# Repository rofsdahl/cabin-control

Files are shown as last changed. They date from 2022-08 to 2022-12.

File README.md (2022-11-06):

# Introduction
Temperature control system for use in a remote location (e.g. a mountain cabin).

The system consists of an ESP32 microcontroller from Espressif and one or more Dallas/Maxim DS18B20 digital temperature sensors. The desired temperature is achieved by continuously switching on/off one or more electrical heaters using Nexa power plugs (over RF 433 MHz). The ESP32 device periodically connects to the Internet over WiFi, logging the current temperature into a Google spreadsheet. The spreadsheet is also used for setting the desired temperature, which will be transferred to the device during the next synchronization.

The ESP32 code is written in Arduino-style C/C++. Integration with Google spreadsheet is done using Google Apps Script (javascript).

## User interface

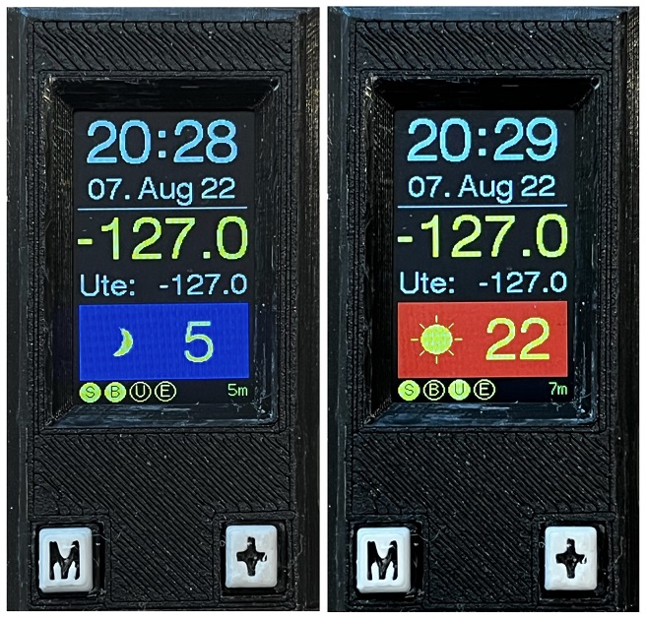
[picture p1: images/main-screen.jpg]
Main screen


The top section displays current date and time. This is updated using NTP, and will be automatically adjusted for DST (daylight saving time). The main temperature is displayed in yellow. Below, the display will cycle through any additional temperature sensors.

The currently set temperature is displayed, and the current temperature mode is indicated:
* :blue_square: :crescent_moon:: frost protection
* :red_square: :sunny:: comfort mode

The bottom line displays the current status of configured power plugs:
* ○: off
* ●: on

The current device activity is displayed at bottom right:
* **Nexa:** Device is transmitting control signals to power plugs (every 5 minutes)
* **WiFi:** Device is connecting to WiFi
* **Time:** Device is updating time from NTP (once per day)
* **Sync:** Device is synchronizing with Google spreadsheet
* **&lt;time&gt;:** Device uptime is displayed when the device is "idle" (only monitoring temperatures)

The two buttons are used for adjusting the desired temperature locally (when you are on-site):
* M: Toggle between temperature modes: frost protection / comfort mode
* +: Increment desired temperature for the currently selected mode. The temperature will roll over from max to min (e.g. 16, 17, ... 24, 25, 16, 17, ...)
* Note! The buttons control the first configured zone (index 0), so this need to be the primary temperature zone.

## Synchronization
Temperatures will be appended to sheet '&lt;yyyy-mm&gt;' in the configured Google spreadsheet (the sheet will be created if it doesn't exist):

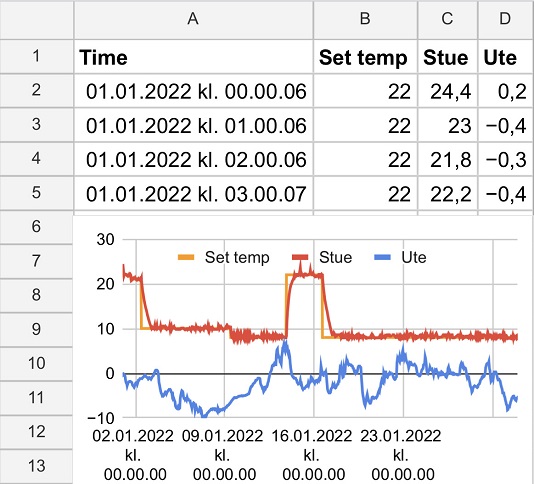
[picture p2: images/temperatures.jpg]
Spreadsheet temperature sheet


Configuration will be read from the sheet 'config', columns A and B (a sheet with default values will be created if it doesn't exist):
* **Last Sync:** Timestamp of last sync
* **Uptime:** Reported uptime from device
* **Error Count:** Errors counted by device (e.g. HTTP timeout)
* **Sync Interval:** Interval between each synchronization (in minutes)
* **&lt;Name&gt; !:** Set (desired) temperature for temperature zone or value (0/1) for manual zone.
  * This value is normally read from the sheet and synced towards the device
  * If the value is changed locally at the device (using the buttons), then the value in the sheet will be updated correspondingly
  * If a formula was used to calculate the cell value (e.g. from a reported temperature), then this formula may get overwritten
* **&lt;Name&gt; °C:** Last reported temperature of zone &lt;Name&gt;
* **&lt;Name&gt; %:** Last reported duty cycle of zone &lt;Name&gt; (percentage heat-on)
* ...

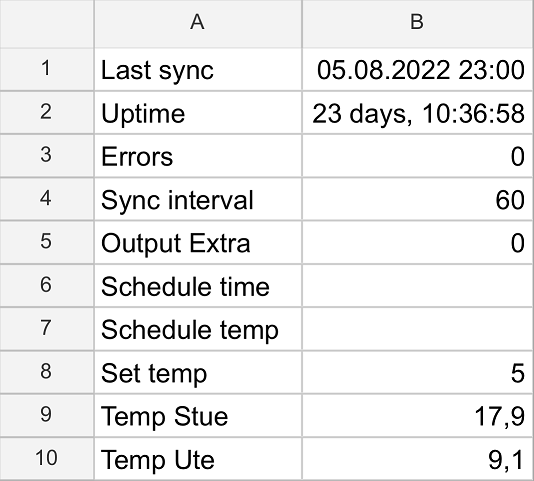
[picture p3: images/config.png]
Spreadsheet config sheet
<br/>
**TODO! Update screenshot**

## Utility menu system
There is also a utility menu system that is invoked by pressing one of the buttons within a couple of seconds after powering up the device.

You control the menu system using the two buttons:
* M: Skip to next menu item
* +: Invoke function

The menu system contains functionality for:
* Reading addresses of connected temperature sensors
* Manually switching Nexa power plugs on/off. This is useful for testing RF communication, and for programming the Nexa Self-Learning power plugs

# Hardware

## LilyGO TTGO T-display ESP32

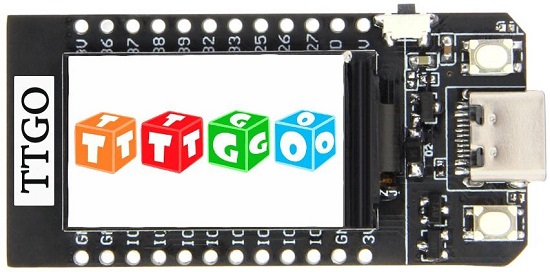
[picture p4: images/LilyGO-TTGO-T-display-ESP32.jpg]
LilyGO TTGO T-display ESP32


[LilyGO TTGO T-display ESP32](http://www.lilygo.cn/prod_view.aspx?TypeId=50044&Id=1126&FId=t3:50044:3)
[GitHub](https://github.com/Xinyuan-LilyGO/TTGO-T-Display)

## Dallas/Maxim DS18B20 Temperature sensor

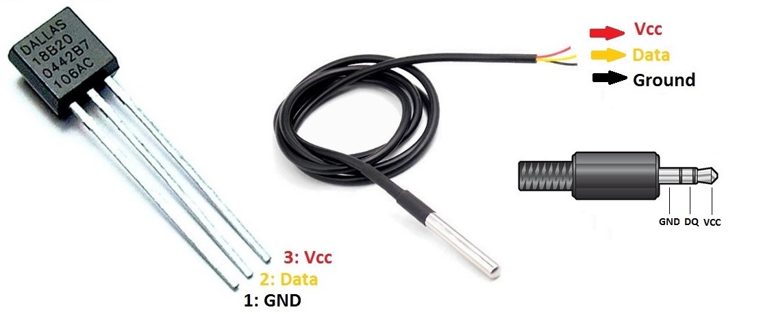
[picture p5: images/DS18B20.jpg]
DS18B20


[Dallas DS18B20 Datasheet](https://datasheets.maximintegrated.com/en/ds/DS18B20.pdf)

## FS1000A/XD-FST RF Radio module

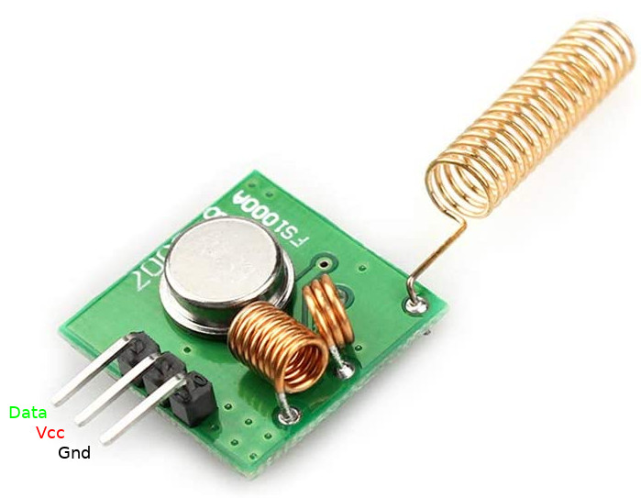
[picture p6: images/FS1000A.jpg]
FS1000A


[FS1000A/XD-FST Datasheet](http://www.mantech.co.za/Datasheets/Products/433Mhz_RF-TX&RX.pdf)

It might be better to use a straight solid core wire antenna (quarter wave-length, 17.3 cm), rather than the antenna coil shown on the picture.

## Wiring

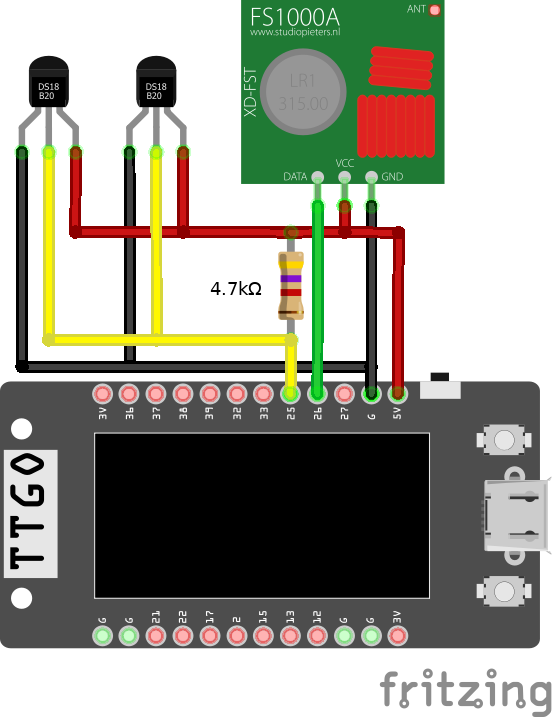
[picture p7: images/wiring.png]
Wiring


# Software installation

## Board
* Install/update the [Arduino IDE](https://www.arduino.cc/en/software)
* In **Preferences** set **Additional Board Manager URLs** to `https://raw.githubusercontent.com/espressif/arduino-esp32/gh-pages/package_esp32_index.json`
* Go to **Tools > Board > Boards Manager** and install **esp32** by Espressif Systems
* Go to **Tools > Board > ESP32 Arduino** and select the board **ESP32 Dev Module**
* The board shall be configured like this:
  * **Board:** ESP32 Dev Module
  * **Upload Speed:** 921600
  * **CPU Frequency:** 240MHz (WiFi/BT)
  * **Flash Frequency:** 80MHz
  * **Flash Mode:** QIO
  * **Flash Size:** 4MB (32Mb)
  * **Partition Scheme:** Default 4MB with spiffs (1.2MB APP/1.5 SPIFFS)
  * **Core Debug Level:** None
  * **PSRAM:** Disabled
  * **Arduino runs on:** Core 1
  * **Events runs on:** Core 1
  * **Port:** (the COM port your board has connected to, see below)
* To determine on which COM port your board connects, do the following steps:
  * If required, install [UART driver](https://www.silabs.com/developers/usb-to-uart-bridge-vcp-drivers)
  * Unplug the board
  * Have a look at **Tools > Port** and remember which ports you see
  * Plug in the board to the USB port
  * Look again at **Tools > Port**
  * The newly added COM port is the COM port of your board and the one you can select

## Libraries
Go to **Tools > Manage libraries** and install the following libraries:
* **TFT_eSPI** by Bodmer
* **DallasTemperature** by Miles Burton, Tim Newsomem, etc.
* **OneWire** by Jim Studt, Tom Pollard, etc.
* **UrlEncode** by Masayuki Sugahara
* **Arduino_JSON** by Arduino
* **Button2** by Lennart Hennigs

## Custom setup file for TTGO T-Display ST7789V
* Edit the file `C:/Users/%USERNAME%/Documents/Arduino/libraries/TFT_eSPI/User_Setup_Select.h`
 and enable the custom setup file for the display:
    ```
    //#include <User_Setup.h>
    #include <User_Setups/Setup25_TTGO_T_Display.h>
    ```
* [Setup file, alt. 1](https://github.com/Xinyuan-LilyGO/TTGO-T-Display/blob/master/TFT_eSPI/User_Setups/Setup25_TTGO_T_Display.h)
* [Setup file, alt. 2](https://github.com/ubcenvcom/TTGO-EkoTuki-Display/blob/master/TTGO_T_Display.h)

# Configuration

## Configuration file
Use the file `config.h.sample` to create a configuration file `config.h` and insert:
* WiFi connection properties
* Google Apps Script ID (see below)
* Zones:
  * Format: {"Name", sensor address, {Nexa id, Nexa id}}
  * Note that the first zone must be the primary temperature zone
  * Sensor address (8 bytes)
    * Set to 0 for manual zone without temperature sensor
    * Tip! Addresses of connected sensors can be read using the utility menu system, and will be printed to serial output - use Serial Monitor at 115000 baud.
  * One or two Nexa power plugs can be configured per zone:
    * Nexa Self-Learning (System Nexa): 4 bytes id >= 0x00000200
    * Nexa Simple: 0x000000<H><U> (H=House, U=Unit)
    * Heat-Link HE35: 0x000001<H><U> (H=House, U=Unit) (e.g. A1 -> 0x1A1) 

## Configuration of Google spreadsheet
Create a Google spreadsheet with associated Apps Script:
* Create a new Google spreadsheet at [Google spreadsheets](https://docs.google.com/spreadsheets/)
* In the spreadsheet, go to **Extensions/Google Apps Script** and create a new script
* Paste the content of `google-apps-script.gs`
* Save the script and deploy it as a **Web app**
* Choose **Execute as yourself** and **access for anyone**
* You must accept that the Apps Script will have access to your spreadsheets
* Save the **Deployment ID** in APPS_SCRIPT_ID in `config.h`

# Reference material

## ESP32
* [FreeRTOS API reference](https://www.freertos.org/a00106.html)
* [Espressif ESP32 FreeRTOS](https://docs.espressif.com/projects/esp-idf/en/latest/esp32/api-reference/system/freertos.html)
* [ESP32 Dual Core tasks](https://randomnerdtutorials.com/esp32-dual-core-arduino-ide)

## TFT
* [Bodmer TFT_eSPI - library targeted at ESP8266 and ESP32 based boards](https://github.com/Bodmer/TFT_eSPI)
* [Bodmer TFT_eSPI - header file](https://github.com/Bodmer/TFT_eSPI/blob/master/TFT_eSPI.h)

## DS18B20 / OneWire protocol
* [Interfacing DS18B20 1-Wire Digital Temperature Sensor with Arduino](https://lastminuteengineers.com/ds18b20-arduino-tutorial)
* [The complete guide for DS18B20 digital temperature sensors with Arduino](https://www.makerguides.com/ds18b20-arduino-tutorial)

## Nexa protocols
The system can communicate using the following protocols:

### Nexa Self-Learning (System Nexa)
This protocol is used by "System Nexa" power plugs, e.g. [MYCR-3500](https://nexa.se/smarta-hem/systemnexa/plugin/mycr-3500), [MYCR-2300](https://nexa.se/smarta-hem/systemnexa/plugin/mycr-2300), [LCMR-1000](https://nexa.se/smarta-hem/systemnexa/inbyggnadsmottagare/lcmr1000) and EYCR-2300.

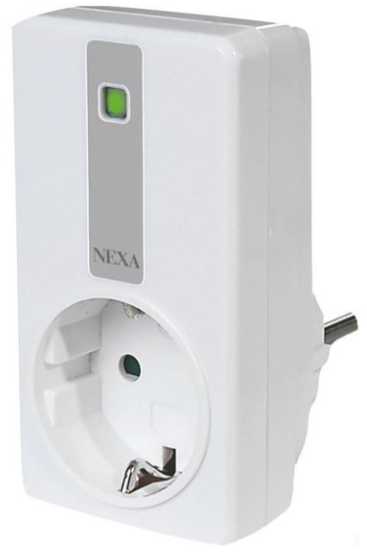
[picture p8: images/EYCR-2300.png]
Nexa EYCR-2300


```
BIT FORMAT:
             ┌───┐
'S' (sync):  │ T │                  10T
             ┘   └───┴───┴───┴───┴───┴───┴───┴───┴───┴───
             ┌───┐                   ┌───┐
'0' bit:     │ T │         5T        │ T │ T
             ┘   └───┴───┴───┴───┴───┘   └───
             <------physical 0------><-ph 1->
             ┌───┐   ┌───┐
'1' bit:     │ T │ T │ T │         5T
             ┘   └───┘   └───┴───┴───┴───┴───
             <-ph 1-><------physical 0------>
             ┌───┐
'P' (pause): │ T │               40T
             ┘   └───┴───┴───┴───//───┴───┴───┴───
T = 250 us

Every logical bit '0' and '1' is sent as two physical bits, where the second one is the inverse of the first one. '0' => '01', '1' => '10'.

PACKET FORMAT:
Each packet consists of a sync bit followed by 26 + 6 bits and ended by a pause bit.
Packets are sent 5 times or more (Nexa) / 6 times or more (Proove/Anslut).
┌───┬────────────────────────────┬───┬───┬────┬────┬───┐
│ S │ UUUUUUUUUUUUUUUUUUUUUUUUUU │ G │ A │ CC │ II │ P │
└───┴────────────────────────────┴───┴───┴────┴────┴───┘
Duration = (11*250) + 32*(8*250) + (41*250) = 77000 us

S = Sync bit.
U = Unique id, 26 bits. This is this code that the reciever "learns" to recognize.
G = Group bit, to address all units in group. All units = '0', one unit = '1'.
A = Activation bit. On = '0', off = '1'.
C = Channel bits. Proove/Anslut = '00', Nexa = '11'.
I = Unit bits for Proove/Anslut. 1 = '00', 2 = '01', 3 = '10', 4 = '11'.
    Unit bits for Nexa.          1 = '11', 2 = '10', 3 = '01', 4 = '00'.
P = Pause bit.
```

### Nexa Simple
This protocol is used by older type Nexa power plugs, where you set house code (A-F) and unit number (1-8) on the device, e.g. SYCR-3500.

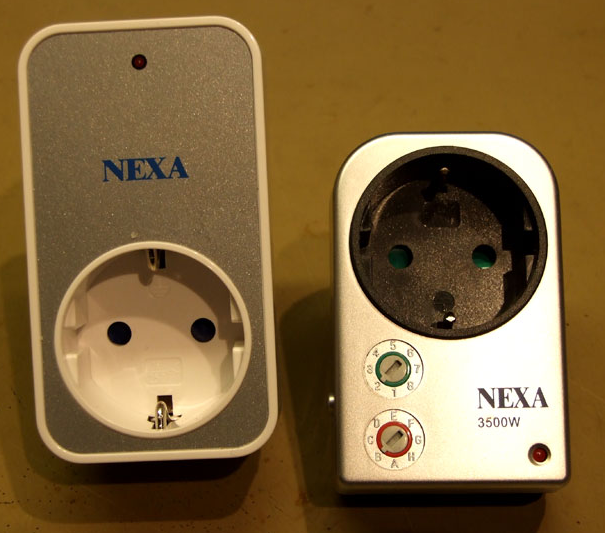
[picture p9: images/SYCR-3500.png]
Nexa SYCR-3500


```
BIT FORMAT:
             ┌───┐           ┌───┐
'0' bit:     │ T │     3T    │ T │     3T
             ┘   └───┴───┴───┘   └───┴───┴───
             ┌───┬───┬───┐   ┌───┬───┬───┐
'1' bit:     │     3T    │ T │     3T    │ T
             ┘           └───┘           └───
             ┌───┐           ┌───┬───┬───┐
'X' bit:     │ T │     3T    │     3T    │ T
             ┘   └───┴───┴───┘           └───
             ┌───┐
'P' (pause): │ T │               32T
             ┘   └───┴───┴───┴───//───┴───┴───┴───
T = 350 us

PACKET FORMAT:
Each packet consists of 12 trinary bits followed by a pause (stop/sync) bit.
Packets are sent 4 times or more.
┌──────┬──────┬─────┬───┬───┐
│ HHHH │ IIII │ ??? │ A │ P │
└──────┴──────┴─────┴───┴───┘
Duration = 12*(8*350) + 33*350 = 45150 us

H = House bits. A = '0000', B = 'X000', C = '0X00', D = 'XX00', ... H = 'XXX0'.
I = Unit bits.  1 = '0000', 2 = 'X000', 3 = '0X00', 4 = 'XX00', ... 8 = 'XXX0'.
? = Unknown bits. Always '0XX'.
A = Activation bit. On = 'X', off = '0'.
P = Pause (stop/sync) bit.
```

### Heat-Link HE-35
This protocol is used by the older HE-35 power plug from Hellmertz Elektronik AS, where you set house code (A-F) and unit number (1-4) on the device. This power plug was previously used together with the [Heat-Link](https://holars.no/kategori/33/heat-link-a224-varmestyrning-ring-hytta-varm/) temperature control system.

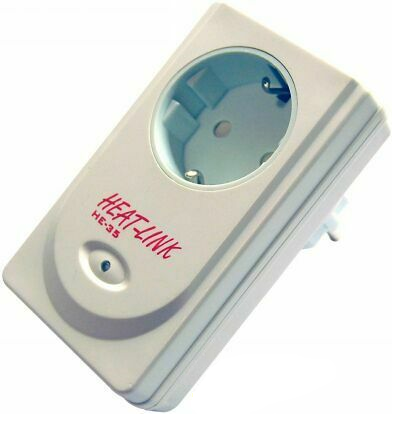
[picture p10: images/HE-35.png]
Heat-Link HE-35


```
BIT FORMAT:
The same as Nexa Simple bit format
T = 420 us

PACKET FORMAT:
Each packet consists of 12 trinary bits followed by a pause (stop/sync) bit.
Packets are sent 7 times or more.
┌────────┬──────┬───┬───┬───┐
│ HHHHHH │ IIII │ ? │ A │ P │
└────────┴──────┴───┴───┴───┘
Duration = 12*(8*420) + 33*420 = 54180 us

H = House bits. A = '0XXXXX', B = 'X0XXXX', C = 'XX0XXX', ... F = 'XXXXX0'.
I = Unit bits.  1 = 'XXX0', 2 = 'XX0X', 3 = 'X0XX', 4 = '0XXX'.
? = Unknown bits. Always '0'.
A = Activation bit. On = 'X', off = '0'.
P = Pause (stop/sync) bit.
```

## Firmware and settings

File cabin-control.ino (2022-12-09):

#include <Preferences.h>
#include <WiFi.h>
#include <TFT_eSPI.h>
#include <SPI.h>
#include <OneWire.h>
#include <DallasTemperature.h>
#include <HTTPClient.h>
#include <UrlEncode.h>
#include <Arduino_JSON.h>
#include "Button2.h"
#include "time.h"

#include "config.h"
#include "typedef.h"
#include "nexa-tx.h"
#include "backlight.h"

#define PIN_LEFT_BUTTON    0
#define PIN_RIGHT_BUTTON  35
#define PIN_SENSOR        25
#define PIN_TX            26

#ifdef DEBUG
#define DEBUG_BEGIN(...)   Serial.begin(__VA_ARGS__)
#define DEBUG_PRINTF(...)  Serial.printf(__VA_ARGS__)
#define DEBUG_PRINTLN(...) Serial.println(__VA_ARGS__)
#else
#define DEBUG_BEGIN(...)   // Blank line - no code
#define DEBUG_PRINTF(...)  // Blank line - no code
#define DEBUG_PRINTLN(...) // Blank line - no code
#endif

#define SEC               (1000UL * 1)
#define MIN               (1000UL * 60)
#define HOUR              (1000UL * 60 * 60)

Preferences preferences;
TFT_eSPI tft = TFT_eSPI();
OneWire oneWire(PIN_SENSOR);
DallasTemperature dallas(&oneWire);
NexaTx nexaTx = NexaTx(PIN_TX);
Backlight backlight;

enum Activity { NONE, NEXA, WIFI, TIME, SYNC };
Activity activity = NONE;
byte setMode;
byte setTemp;
byte prevTemp;
int syncIntervalMin = 60;
bool doReverseSync = false;
bool savePrefsPending = false;
bool wifiSuccess = true;
int errCount = 0;
unsigned long tLastTempRead = 0;
unsigned long tLastNexaUpdate = 0;
unsigned long tLastNtpSync = 0;
unsigned long tLastSync = 0;
unsigned long tLastReport = 0;
unsigned long tLastDisplayUpdate = 0;
unsigned long tLastWifiFailure = 0;

const byte minTemp[] = { 5, 16};
const byte maxTemp[] = {15, 25};
const int numZones = sizeof(zones) / sizeof(zones[0]);
const unsigned long displayUpdateInterval = 1 * SEC;
const unsigned long tempReadInterval = 5 * SEC;
const unsigned long nexaUpdateInterval = 5 * MIN;
const unsigned long ntpSyncInterval = 24 * HOUR;
const unsigned long displayDimTimeout = 1 * MIN;
const unsigned long keypressTimeout = 5 * SEC;
const unsigned long wifiConnectTimeout = 10 * SEC;
const unsigned long wifiRetryTimeout = 1 * MIN;
const unsigned long httpResponseTimeout = 20 * SEC;

////////////////////////////////////////////////////////////////////////////////
void enableWiFi() {
  WiFi.disconnect(false);
  WiFi.mode(WIFI_STA);
  delay(200);

  DEBUG_PRINTLN("Connecting to WiFi...");
  WiFi.begin(WIFI_SSID, WIFI_PASSWORD);

  unsigned long tStart = millis();
  while (millis() - tStart < wifiConnectTimeout) {
    if (WiFi.status() == WL_CONNECTED) {
      DEBUG_PRINTF("-> IP address: %s\n", WiFi.localIP().toString());
      tLastWifiFailure = millis() - wifiRetryTimeout;
      wifiSuccess = true;
      return;
    }
    delay(100);
  }
  DEBUG_PRINTLN("-> FAILED!");
  tLastWifiFailure = millis();
  wifiSuccess = false;
}

void disableWiFi() {
  WiFi.disconnect(true);
  WiFi.mode(WIFI_OFF);
  DEBUG_PRINTLN("WiFi disconnected!");
}

////////////////////////////////////////////////////////////////////////////////

unsigned long getUptimeMillis() {
  return (int64_t)esp_timer_get_time() / 1000;
}

String toDurationStr(unsigned long ms) {
  unsigned long t = ms / 1000;
  if (t < 60)
    return (String)t + "s";
  t /= 60;
  if (t < 60)
    return (String)t + "m";
  t /= 60;
  if (t < 24)
    return (String)t + "h";
  t /= 24;
  return (String)t + "d";
}

uint8_t weekday(time_t unixTime) {
  // Calculate day of week Sun-Sat as an integer 0-6
  // 1970-01-01 was a Thursday (4)
  return ((unixTime / (24 * 60 * 60)) + 4) % 7;
}

time_t lastSundayOf(int year, int month) {
  struct tm timeinfo;
  timeinfo.tm_year = year;
  timeinfo.tm_mon = month - 1;
  timeinfo.tm_mday = 31;
  timeinfo.tm_hour = 2;
  timeinfo.tm_sec = 0;
  timeinfo.tm_min = 0;
  time_t lastDayOfMonth = mktime(&timeinfo);
  timeinfo.tm_mday = 31 - weekday(lastDayOfMonth);
  return mktime(&timeinfo);
}

int calculateDstOffset() {
  struct tm timeinfo;
  getLocalTime(&timeinfo);
  time_t now = mktime(&timeinfo);
  time_t dstBegin = lastSundayOf(timeinfo.tm_year, 3);
  time_t dstEnd = lastSundayOf(timeinfo.tm_year, 10);
  return (now > dstBegin && now < dstEnd) ? 1 : 0;
}

void adjustTime() {
  DEBUG_PRINTLN("NTP sync...");
  static int dstOffset = 0;
  int lastDstOffset;
  do {
    const int timezone = 1;
    DEBUG_PRINTF("-> DST %d\n", dstOffset);
    configTime(timezone * 60 * 60, dstOffset * 60 * 60, "pool.ntp.org", "time.nist.gov");
    lastDstOffset = dstOffset;
    dstOffset = calculateDstOffset();

  } while (dstOffset != lastDstOffset);
}

////////////////////////////////////////////////////////////////////////////////

int getNumTempZones() {
  int numTempZones = 0;
  for (int i = 0; i < numZones; i++) {
    if (zones[i].sensorId != 0) {
      numTempZones++;
    }
  }
  return numTempZones;
}

int getTempZone(int n) {
  int t = 0;
  for (int i = 0; i < numZones; i++) {
    if (zones[i].sensorId != 0) {
      if (n == t) return i;
      else t++;
    }
  }
  return -1;
}

byte normalizeValue(byte value, byte minValue, byte maxValue) {
  if (value < minValue)
    return minValue;
  else if (value > maxValue)
    return maxValue;
  else
    return value;
}

byte normalizeValue(byte value, int zone) {
  byte minValue = zones[zone].sensorId != 0 ? minTemp[0] : 0;
  byte maxValue = zones[zone].sensorId != 0 ? maxTemp[1] : 1;
  return normalizeValue(value, minValue, maxValue);
}

void restorePreferences() {
  DEBUG_PRINTLN("Restore preferences...");

  for (int i = 0; i < numZones; i++) {
    if (zones[i].nexas[0] != 0) {
      byte rawValue = preferences.getUChar(zones[i].name, 0);
      zones[i].value = normalizeValue(rawValue, i);
      if (zones[i].value != rawValue) {
        savePrefsPending = true;
      }
      DEBUG_PRINTF("<- Zone %s: %d (raw: %d)\n", zones[i].name, zones[i].value, rawValue);
    }
  }

  setTemp = zones[0].value;
  setMode = setTemp >= minTemp[1] ? 1 : 0;

  byte prevMode = (setMode + 1) % 2;
  byte rawValue = preferences.getUChar("prevTemp", 0);
  prevTemp = normalizeValue(rawValue, minTemp[prevMode], maxTemp[prevMode]);
  if (prevTemp != rawValue) {
    savePrefsPending = true;
  }
  DEBUG_PRINTF("<- prevTemp: %d (raw: %d)\n", prevTemp, rawValue);
}

void savePreferences() {
  DEBUG_PRINTLN("Save preferences...");
  for (int i = 0; i < numZones; i++) {
    if (zones[i].nexas[0] != 0) {
      DEBUG_PRINTF("-> Zone %s: %d\n", zones[i].name, zones[i].value);
      preferences.putUChar(zones[i].name, zones[i].value);
    }
  }
  DEBUG_PRINTF("-> prevTemp: %d\n", prevTemp);
  preferences.putUChar("prevTemp", prevTemp);
}

////////////////////////////////////////////////////////////////////////////////

void readTemperatures() {
  //DEBUG_PRINTLN("Read temperatures...");
  dallas.requestTemperatures();
  for (int i = 0; i < numZones; i++) {
    if (zones[i].sensorId != 0) {
      DeviceAddress deviceAddr;
      uint64_t sensorId = zones[i].sensorId;
      for (int j = 7; j >= 0; j--) {
        deviceAddr[j] = sensorId & 0x00000000000000FF;
        sensorId >>= 8;
      }
      zones[i].temp = dallas.getTempC(deviceAddr);
      //DEBUG_PRINTF("<- %s (0x%016llX): %.2f\n", zones[i].name, zones[i].sensorId, zones[i].temp);
    }
  }
}

void updateNexas() {
  DEBUG_PRINTLN("Update Nexas...");
  for (int i = 0; i < numZones; i++) {
    bool newState = zones[i].state;
    if (zones[i].sensorId != 0) {
      float tempOffset = zones[i].state ? 0.1 : -0.1;
      newState = zones[i].temp < (zones[i].value + tempOffset);
    }
    else {
      newState = zones[i].value > 0;
    }

    // Start / stop on-timer
    unsigned long tNow = millis();
    if (!zones[i].state && newState) {
      zones[i].tOn = tNow;
      DEBUG_PRINTF(".. Zone %s ON at %d, accumulated = %d\n", zones[i].name, zones[i].tOn, zones[i].tAccu);
    }
    if (zones[i].state && !newState) {
      unsigned long tPeriod = tNow - zones[i].tOn;
      zones[i].tAccu += tPeriod;
      DEBUG_PRINTF(".. Zone %s OFF at %d, period = %d, accumulated = %d\n", zones[i].name, tNow, tPeriod, zones[i].tAccu);
    }

    // Update state
    zones[i].state = newState;

    // Transmit current zone state for all Nexa power plugs
    for (int j = 0; j < NEXAS_PER_ZONE; j++) {
      if (zones[i].nexas[j] != 0) {
        DEBUG_PRINTF("-> Zone %s (Nexa %d): %d\n", zones[i].name, j + 1, zones[i].state);

        NexaType type = SIMPLE;
        if (zones[i].nexas[j] > 0x00000100) type = HE35;
        if (zones[i].nexas[j] > 0x00000200) type = LEARN;
        unsigned long id = zones[i].nexas[j] & (type == LEARN ? 0xFFFFFFFF : 0x000000FF);
        nexaTx.transmit(type, id, zones[i].state);
      }
    }
  }
}

void synchronizeWithRemote() {
  DEBUG_PRINTLN("Synchronize with remote...");
  unsigned long tNow = millis();

  String url = "https://script.google.com/macros/s/" APPS_SCRIPT_ID "/exec?uptime=";
  url += getUptimeMillis() / 1000;
  url += "&errorCount=";
  url += errCount;

  for (int i = 0; i < numZones; i++) {

    // TODO: Calculate duty cycle for all zones with sensor and Nexas
    int dutyCyclePercent;
    if (i == 0) {
      // Accumulate on-timer, calculate and report duty cycle, reset on-timer
      if (zones[i].state) {
        unsigned long tPeriod = tNow - zones[i].tOn;
        zones[i].tAccu += tPeriod;
        zones[i].tOn = tNow;
      }
      // TODO: Integer division with rounding (995/1000 should be 100%)
      dutyCyclePercent = zones[i].tAccu * 100 / (tNow - tLastReport);
      DEBUG_PRINTF(".. Zone %s duty cycle = %d %% (%d*100/(%d-%d))\n", zones[i].name, dutyCyclePercent, zones[i].tAccu, tNow, tLastReport);
      zones[i].tAccu = 0;
    }

    // Zone:<name>;<value|blank|NA>;<temp|blank>;<duty cycle|blank>
    String zoneParam = urlEncode(zones[i].name) + ";";

    // Reverse sync value, blank if no reverse sync or "NA" for zone without Nexas
    if (zones[i].nexas[0] == 0)
      zoneParam += "NA";
    // TODO: Support reverse sync of all zones? (may overwrite cell formulas)
    else if (doReverseSync && i == 0)
      zoneParam += zones[i].value;
    zoneParam += ";";

    if (zones[i].sensorId != 0)
      zoneParam += String(zones[i].temp, 1);
    zoneParam += ";";

    // TODO: Report duty cycle for all zones with sensor and Nexas
    if (i == 0)
      zoneParam += dutyCyclePercent;

    DEBUG_PRINTF("-> Zone %s\n", zoneParam.c_str());
    url += "&zone=" + zoneParam;
  }

  tLastReport = tNow;
  doReverseSync = false;

  int responseCode = 0;
  int maxRedirects = 3;

  do {
    HTTPClient http;
    http.begin(url.c_str());
    DEBUG_PRINTF("HTTP request: %s\n", url.c_str());
    const char * headerKeys[] = {"Location"};
    http.collectHeaders(headerKeys, sizeof(headerKeys) / sizeof(char*));
    http.setTimeout(httpResponseTimeout);
    responseCode = http.GET();
    DEBUG_PRINTF("HTTP response code: %d\n", responseCode);

    if (responseCode == 200) {
      String payload = http.getString();
      DEBUG_PRINTF("HTTP response: %s\n", payload.c_str());
      http.end();

      JSONVar json = JSON.parse(payload);
      if (JSON.typeof(json) == "object") {

        for (int i = 0; i < numZones; i++) {
          // Skip zones without Nexas
          if (zones[i].nexas[0] == 0)
            continue;
          if (json[String("zone.") + zones[i].name] == null)
            continue;

          int rawValue = (int)json[String("zone.") + zones[i].name];
          int value = normalizeValue(rawValue, i);
          if (rawValue != value) {
            // Value normalized - trigger another sync to update sheet
            tLastSync = millis() - syncIntervalMin * MIN;
            doReverseSync = true;
          }

          DEBUG_PRINTF("<- Zone %s: %d (raw: %d, prev: %d)\n", zones[i].name, value, rawValue, zones[i].value);

          // Set new value, save prefs and trigger update of Nexas
          if (value != zones[i].value) {
            zones[i].value = value;
            savePrefsPending = true;
            tLastNexaUpdate = millis() - nexaUpdateInterval;
          }
          if (i == 0) {
            byte currTemp = setTemp;
            byte currMode = setMode;
            setTemp = zones[0].value;
            setMode = setTemp >= minTemp[1] ? 1 : 0;
            if (setMode != currMode) {
              prevTemp = currTemp;
            }
          }
        }

        int value = (int)json["syncInterval"];
        DEBUG_PRINTF("<- Sync Interval: %d\n", value);
        if (value > 0) {
          syncIntervalMin = value;
        }
      }
    }

    if (responseCode == 302) {
      url = http.header("Location");
    }

    // TODO: Improve error handling. Have seen -1 and -11, meaning what? Timeout?
    // TODO: 4xx from Google should also be handled
    // TODO: Display error status on device
    // TODO: Add reference to HTTPClient doc
    if (responseCode < 0) {
      errCount++;
    }

    http.end();

  } while (responseCode == 302 && maxRedirects-- > 0);
}

void controlTask(void *params) {

  tLastTempRead = millis() - tempReadInterval;
  tLastNexaUpdate = millis() - nexaUpdateInterval;
  tLastNtpSync = millis() - ntpSyncInterval;
  tLastSync = millis() - syncIntervalMin * MIN;
  tLastWifiFailure = millis() - wifiRetryTimeout;

  int dayMinDone = -1;

  while (true) {
    vTaskDelay(10);

    if (savePrefsPending) {
      savePrefsPending = false;
      savePreferences();
    }

    if (millis() - tLastTempRead >= tempReadInterval) {
      tLastTempRead = millis();
      readTemperatures();
    }

    if (millis() - tLastNexaUpdate >= nexaUpdateInterval) {
      activity = NEXA;
      tLastNexaUpdate = millis();
      updateNexas();
      activity = NONE;
    }

    struct tm timeinfo;
    getLocalTime(&timeinfo, 100);
    int dayMin = timeinfo.tm_hour * 60 + timeinfo.tm_min;

    bool doScheduledSync = dayMin % syncIntervalMin == 0 && dayMin != dayMinDone;

    if (millis() - tLastWifiFailure < wifiRetryTimeout) {
      continue;
    }

    if (doScheduledSync || millis() - tLastSync >= syncIntervalMin * MIN) {

      activity = WIFI;
      enableWiFi();
      activity = NONE;

      if (WiFi.status() == WL_CONNECTED) {

        // NTP sync at 03:00
        if (dayMin == 3 * 60 || millis() - tLastNtpSync >= ntpSyncInterval) {
          activity = TIME;
          tLastNtpSync = millis();
          adjustTime();
          activity = NONE;
        }

        activity = SYNC;
        tLastSync = millis();
        dayMinDone = dayMin;
        synchronizeWithRemote();
        activity = NONE;
      }

      disableWiFi();
    }
  }
}

////////////////////////////////////////////////////////////////////////////////

void toggleMode(Button2& btn) {
  if (!backlight.isBright()) {
    backlight.setBright();
  } else {
    setMode = (setMode + 1) % 2;
    setTemp = prevTemp;
    prevTemp = zones[0].value;
    zones[0].value = setTemp;

    // Trigger update of display, Nexas and remote sync
    tLastDisplayUpdate = millis() - displayUpdateInterval;
    tLastNexaUpdate = millis() - nexaUpdateInterval + keypressTimeout;
    tLastSync = millis() - syncIntervalMin * MIN + keypressTimeout;
    doReverseSync = true;
    savePrefsPending = true;
  }
}

void increaseTemp(Button2& btn) {
  if (!backlight.isBright()) {
    backlight.setBright();
  } else {
    setTemp++;
    if (setTemp > maxTemp[setMode]) {
      setTemp = minTemp[setMode];
    }
    zones[0].value = setTemp;

    // Trigger update of display, Nexas and remote sync
    tLastDisplayUpdate = millis() - displayUpdateInterval;
    tLastNexaUpdate = millis() - nexaUpdateInterval + keypressTimeout;
    tLastSync = millis() - syncIntervalMin * MIN + keypressTimeout;
    doReverseSync = true;
    savePrefsPending = true;
  }
}

void buttonTask(void *params) {
  Button2 leftBtn = Button2(PIN_LEFT_BUTTON);
  leftBtn.setPressedHandler(toggleMode);

  Button2 rightBtn = Button2(PIN_RIGHT_BUTTON);
  rightBtn.setPressedHandler(increaseTemp);

  while (true) {
    vTaskDelay(1);

    backlight.loop();
    leftBtn.loop();
    rightBtn.loop();
  }
}

////////////////////////////////////////////////////////////////////////////////

void displayTask(void *params) {
  tft.fillScreen(TFT_BLACK);
  backlight.begin(TFT_BL, 8, 20, 255, displayDimTimeout);
  bool isFirstDisplay = true;

  while (true) {
    vTaskDelay(1);

    if (millis() - tLastDisplayUpdate >= displayUpdateInterval) {
      tLastDisplayUpdate = millis();

      struct tm timeinfo;
      getLocalTime(&timeinfo, 100);
      char buf[20];
      strftime(buf, sizeof(buf), "  %H:%M  ", &timeinfo);

      // Time
      int y = 0;
      tft.setTextDatum(TC_DATUM);
      tft.setTextColor(TFT_LIGHTGREY, TFT_BLACK);
      tft.drawString(buf, 67, y, 6);

      // Date
      y = 48;
      strftime(buf, sizeof(buf), "  %d. %b %y  ", &timeinfo);
      tft.drawString(buf, 67, y, 4);
      tft.drawLine(0, y + 27, 135, y + 27, TFT_LIGHTGREY);

      // Main temp
      y = 82;
      tft.setTextColor(TFT_YELLOW, TFT_BLACK);
      int x = tft.drawFloat(zones[0].temp, 1, 67, y, 6);
      tft.fillRect(0, y, 67 - x / 2, 48, TFT_BLACK);
      tft.fillRect(67 + x / 2, y, 68 - x / 2, 48, TFT_BLACK);

      // Extra temp
      y = 130;
      int numTempZones = getNumTempZones();
      if (numTempZones >= 2) {
        int i = 1 + ((millis() / 10000) % (numTempZones - 1));
        i = getTempZone(i);
        tft.setTextColor(TFT_LIGHTGREY, TFT_BLACK);
        tft.setTextDatum(TL_DATUM);
        int x1 = tft.drawString(zones[i].name, 0, y, 4);
        x1 += tft.drawString(":", x1, y, 4);
        tft.setTextDatum(TR_DATUM);
        int x2 = 135 - tft.drawFloat(zones[i].temp, 1, 135, y, 4);
        tft.fillRect(x1, y, x2 - x1, 26, TFT_BLACK);
      }

      // Set temp
      y = 170;
      static byte lastDisplayedTemp = -1;
      if (setTemp != lastDisplayedTemp) {
        uint16_t col = setMode == 1 ? TFT_RED : TFT_BLUE;
        tft.setTextColor(TFT_YELLOW, col);
        tft.setTextDatum(TC_DATUM);

        int x = tft.drawNumber(setTemp, 67 + 28, y, 6);
        tft.fillRect(0, y, 67 + 28 - x / 2, 48, col);
        tft.fillRect(67 + 28 + x / 2, y, 68 - 28 - x / 2, 48, col);
        tft.fillRect(0, y - 13, 135, 13, col);
        tft.fillRect(0, y + 48, 135, 3, col);
        lastDisplayedTemp = setTemp;

        if (setMode == 1) {
          // Sun
          tft.drawLine(30 - 20, y + 18, 30 + 20, y + 18, TFT_YELLOW);
          tft.drawLine(30, y + 18 - 20, 30, y + 18 + 20, TFT_YELLOW);
          tft.drawLine(30 - 13, y + 18 - 13, 30 + 13, y + 18 + 13, TFT_YELLOW);
          tft.drawLine(30 - 13, y + 18 + 13, 30 + 13, y + 18 - 13, TFT_YELLOW);
          tft.fillCircle(30, y + 18, 14, col);
          tft.fillCircle(30, y + 18, 12, TFT_YELLOW);
        }
        else {
          // Moon
          tft.fillCircle(30, y + 18, 12, TFT_YELLOW);
          tft.fillCircle(30 - 12, y + 18 - 3, 16, col);
        }
      }

      // Zone state
      y = 223;
      tft.setTextDatum(TL_DATUM);

      int n = 0;
      for (int i = 0; i < numZones; i++) {
        if (zones[i].nexas[0] != 0) {
          // Ensure display of initial Nexa state
          if (zones[i].state != zones[i].lastDisplayedState || isFirstDisplay) {
            if (zones[i].state) {
              tft.fillCircle(n * 20 + 8, y + 8, 8, TFT_YELLOW);
              tft.setTextColor(TFT_BLACK);
              tft.drawChar(zones[i].name[0], n * 20 + 5, y, 2);
            }
            else {
              tft.fillCircle(n * 20 + 8, y + 8, 8, TFT_BLACK);
              tft.drawCircle(n * 20 + 8, y + 8, 8, TFT_YELLOW);
              tft.setTextColor(TFT_YELLOW);
              tft.drawChar(zones[i].name[0], n * 20 + 5, y, 2);
            }
            zones[i].lastDisplayedState = zones[i].state;
          }
          n++; //Next position
        }
      }

      // Activity / uptime
      y = 223;
      String text = toDurationStr(getUptimeMillis());
      if      (activity == NEXA) text = "Nexa";
      else if (activity == WIFI) text = "WiFi";
      else if (activity == TIME) text = "Time";
      else if (activity == SYNC) text = "Sync";

      tft.setTextColor(wifiSuccess ? TFT_GREEN : TFT_RED, TFT_BLACK);
      tft.setTextDatum(TR_DATUM);
      x = tft.drawString(text, 135, y, 2);
      tft.fillRect(100, y, 35 - x, 16, TFT_BLACK);
    }
    isFirstDisplay = false;
  }
}

////////////////////////////////////////////////////////////////////////////////

void displaySensors() {
  tft.fillScreen(TFT_BLACK);
  tft.setTextColor(TFT_YELLOW, TFT_BLACK);
  tft.drawString("Sensors:", 0, 0, 4);
  tft.drawLine(0, 26, 135, 26, TFT_YELLOW);
  tft.setTextColor(TFT_LIGHTGREY, TFT_BLACK);

  dallas.begin();
  int numSensors = dallas.getDeviceCount();

  for (int i = 0; i < numSensors; i++) {
    DeviceAddress address;
    dallas.getAddress(address, i);

    char buf[17];
    snprintf(buf, sizeof(buf), "%02X%02X%02X%02X%02X%02X%02X%02X",
             address[0], address[1], address[2], address[3],
             address[4], address[5], address[6], address[7]);
    tft.drawString(buf, 0, 32 + i * 16, 2);
    DEBUG_PRINTF("Sensor %d: 0x%s\n", i + 1, buf);
  }
}

const char* menuItems[] = {"Select Nexa", "Turn on", "Turn off", "Turn on/off", "Sensors", "Exit"};
int selectedMenuItem = 0;
int selectedNexa = 0;
int selectedZone = 0;

void displayMenuItems() {
  int numMenuItems = sizeof(menuItems) / sizeof(menuItems[0]);
  for (int i = 0; i < numMenuItems; i++) {
    uint16_t fgCol = selectedMenuItem == i ? TFT_BLACK : TFT_LIGHTGREY;
    uint16_t bgCol = selectedMenuItem == i ? TFT_LIGHTGREY : TFT_BLACK;
    tft.setTextColor(fgCol, bgCol);
    int x = tft.drawString(menuItems[i], 0, 32 + i * 26, 4);
    tft.fillRect(x, 32 + i * 26, 135 - x, 26, bgCol);
  }
}
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
void loop() {
  vTaskDelay(1);
}

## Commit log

2022-09-26 Apps script - read outputs after writing temperatures
2022-10-06 On-timer / duty cycle
2022-10-09 URL encode + debug print
2022-10-28 Sensor address as uint64_t + renaming stuff
2022-12-04 Fix unsigned long overflow for millis
